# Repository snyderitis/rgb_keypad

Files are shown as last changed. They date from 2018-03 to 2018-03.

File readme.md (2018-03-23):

# 20keyrgb

20keyrgb

A short description of the keyboard/project

Keyboard Maintainer: [Snyderitis](https://github.com/snyderitis)  
Hardware Supported: The kicad files for the PCB are in the "RGB keyboard" folder. 
Hardware Availability: I used WS2812B leds with 0.1uF SMD capacitors and a teensy. In the future it would be wiser to use an Arduino Pro mini as they're essentially the same and have the same pin layout.

Make example for this keyboard (after setting up your build environment):

    make 20keyrgb:default

See [build environment setup](https://docs.qmk.fm/build_environment_setup.html) then the [make instructions](https://docs.qmk.fm/make_instructions.html) for more information.

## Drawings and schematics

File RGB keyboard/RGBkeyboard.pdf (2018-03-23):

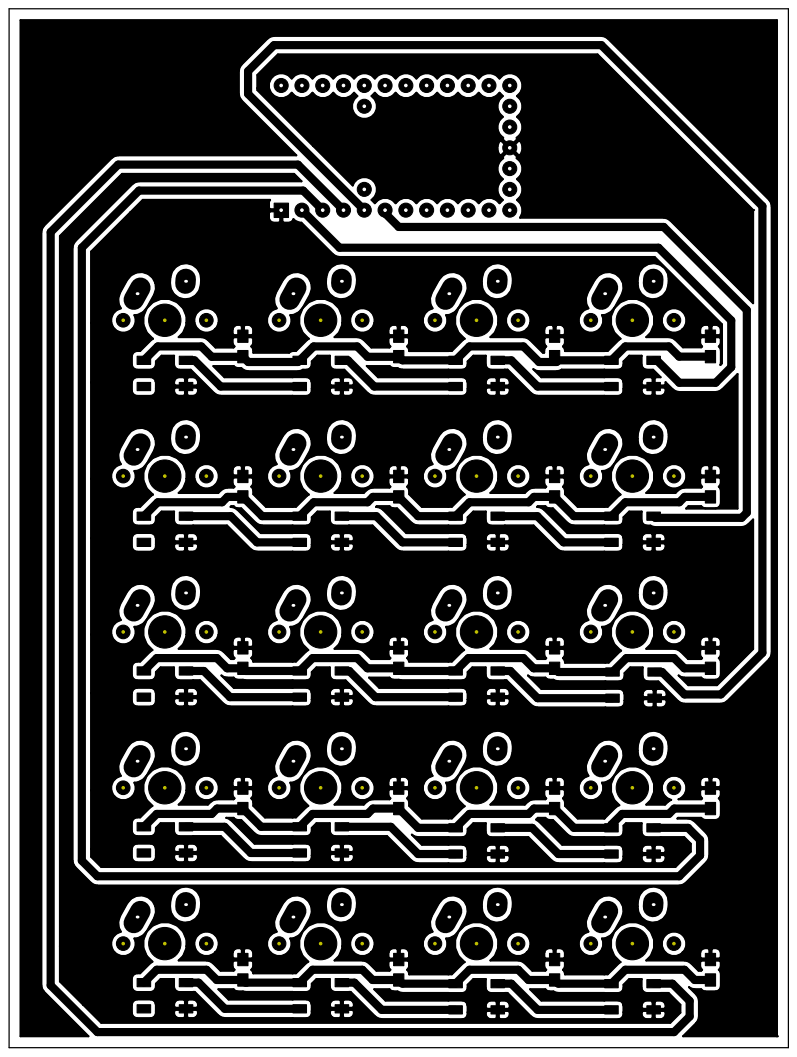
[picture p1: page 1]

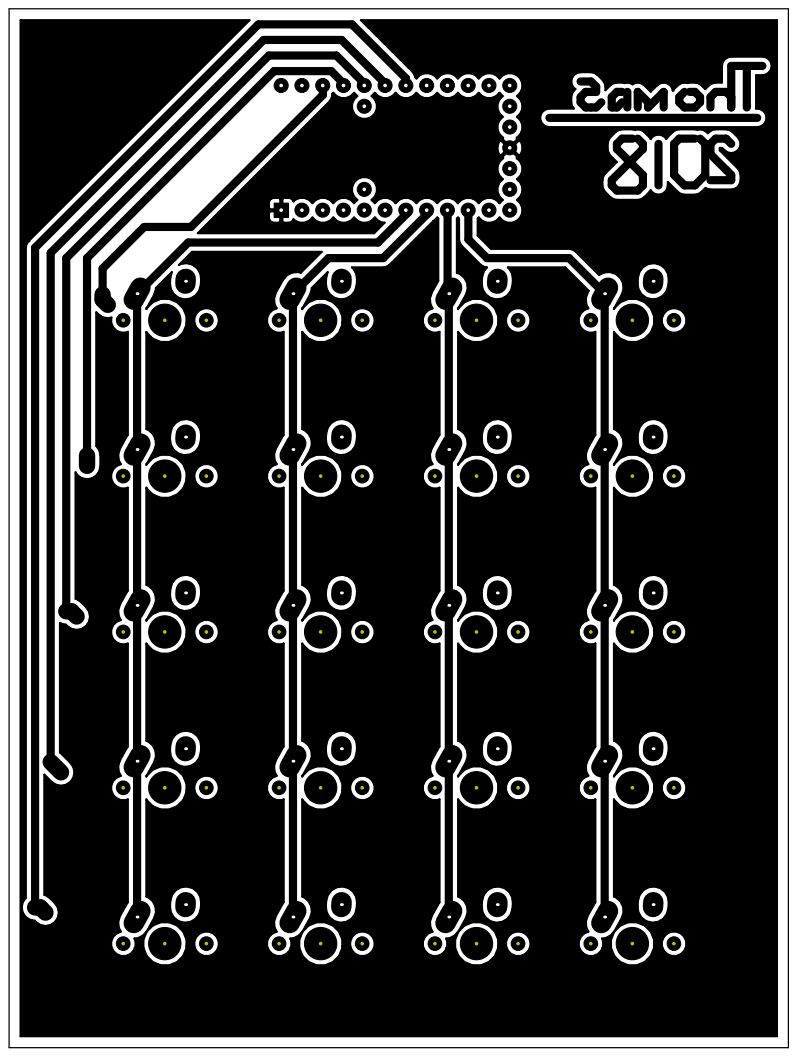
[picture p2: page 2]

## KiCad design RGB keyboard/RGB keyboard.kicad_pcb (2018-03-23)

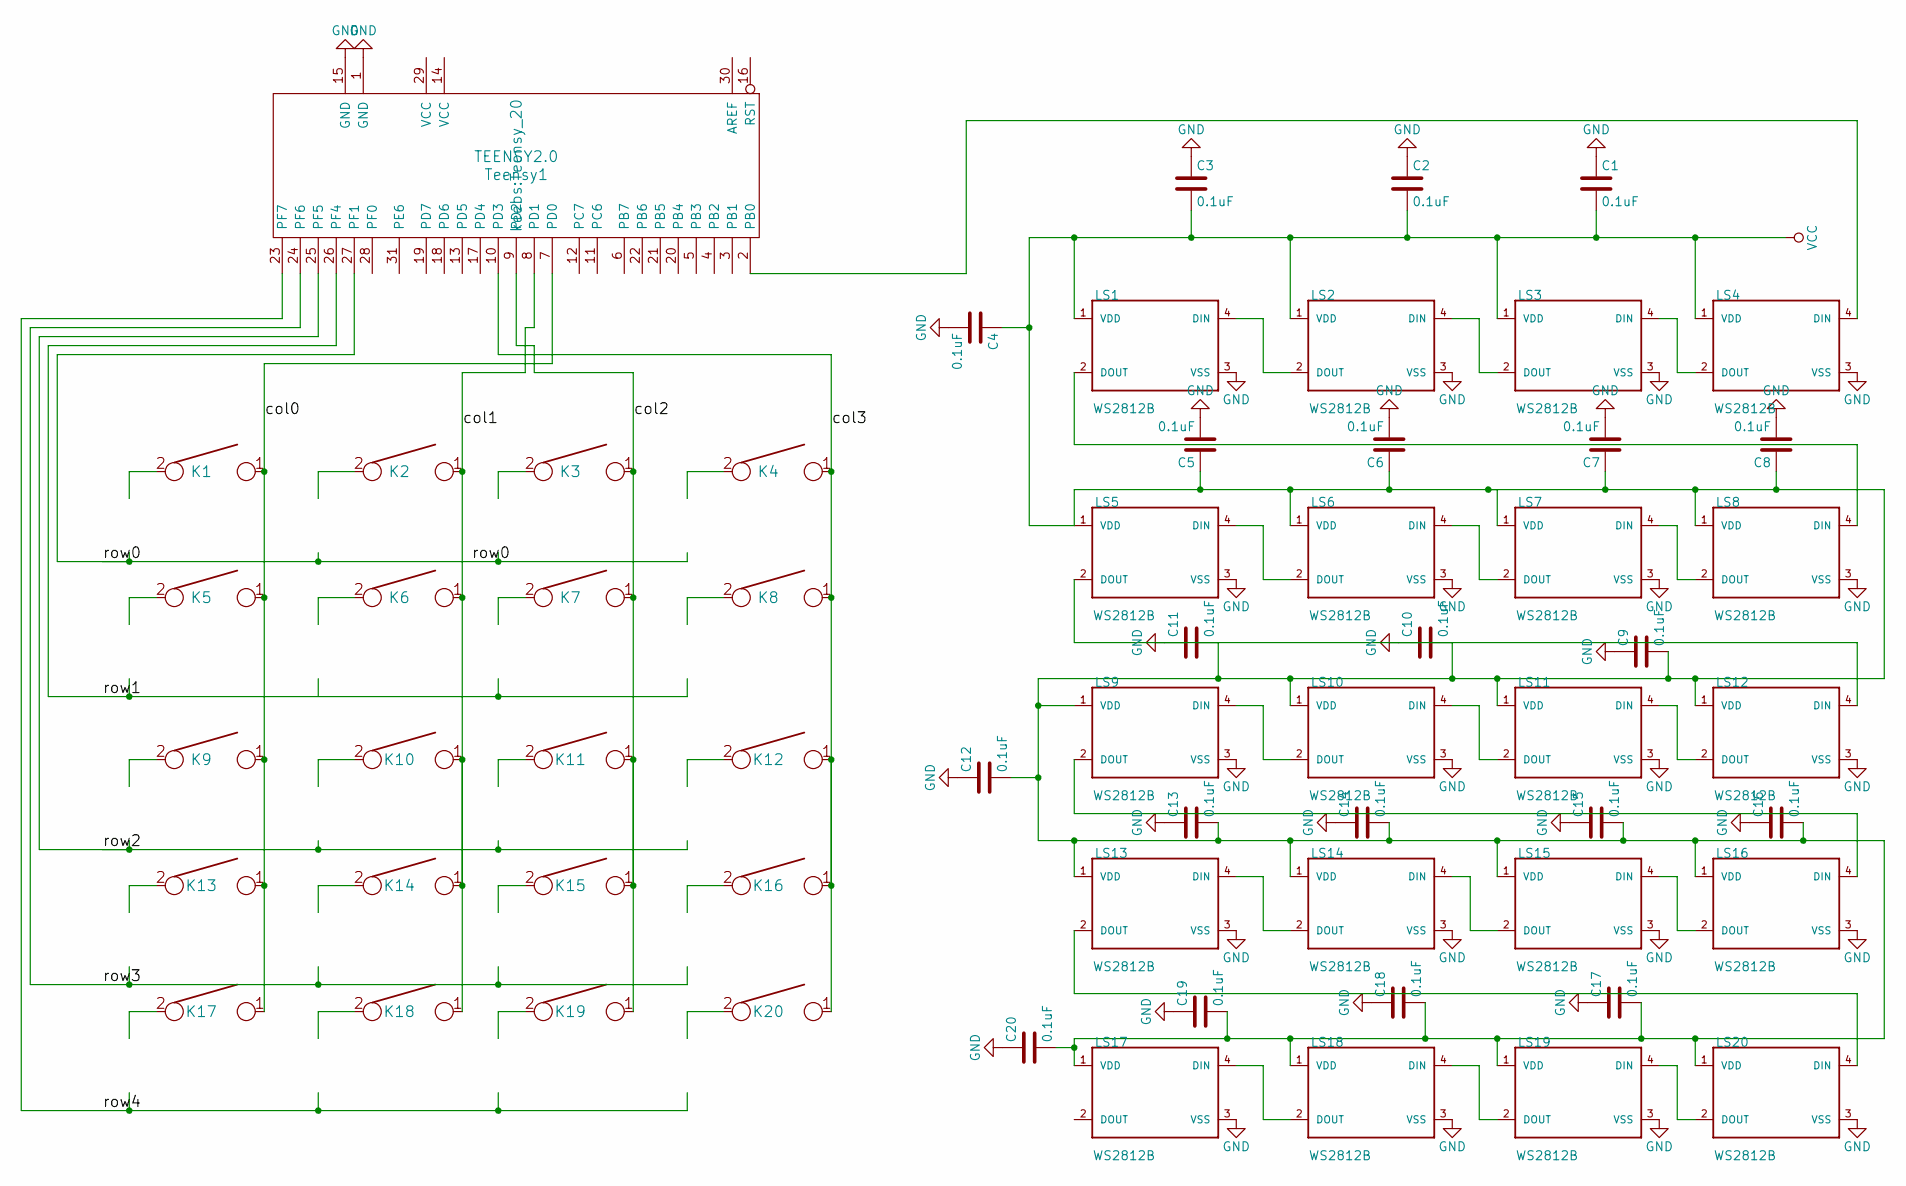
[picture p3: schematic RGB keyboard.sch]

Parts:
C1, C2, C3, C4, C5, C6, C7, C8, C9, C10, C11, C12, C13, C14, C15, C16, C17, C18, C19, C20: 0.1uF; C_0805_HandSoldering
K1, K2, K3, K4, K5, K6, K7, K8, K9, K10, K11, K12, K13, K14, K15, K16, K17, K18, K19, K20: KEYSW; Mx_Alps_100
LS1, LS2, LS3, LS4, LS5, LS6, LS7, LS8, LS9, LS10, LS11, LS12, LS13, LS14, LS15, LS16, LS17, LS18, LS19, LS20: WS2812B
Teensy1: TEENSY2.0; Teensy_20

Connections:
/col0: K1.1, K5.1, K9.1, K13.1, K17.1, Teensy1.7 (PD0)
/col1: K2.1, K6.1, K10.1, K14.1, K18.1, Teensy1.8 (PD1)
/col2: K3.1, K7.1, K11.1, K15.1, K19.1, Teensy1.9 (PD2)
/col3: K4.1, K8.1, K12.1, K16.1, K20.1, Teensy1.10 (PD3)
/row0: Teensy1.27 (PF1)
/row1: Teensy1.26 (PF4)
/row2: Teensy1.25 (PF5)
/row3: Teensy1.24 (PF6)
/row4: Teensy1.23 (PF7)
unnamed: LS1.2 (DOUT), LS8.4 (DIN)
unnamed: LS1.4 (DIN), LS2.2 (DOUT)
unnamed: LS2.4 (DIN), LS3.2 (DOUT)
unnamed: LS3.4 (DIN), LS4.2 (DOUT)
unnamed: LS4.4 (DIN), Teensy1.2 (PB0)
unnamed: LS5.4 (DIN), LS6.2 (DOUT)
unnamed: LS6.4 (DIN), LS7.2 (DOUT)
unnamed: LS7.4 (DIN), LS8.2 (DOUT)
unnamed: LS9.4 (DIN), LS10.2 (DOUT)
unnamed: LS10.4 (DIN), LS11.2 (DOUT)
unnamed: LS11.4 (DIN), LS12.2 (DOUT)
unnamed: LS13.2 (DOUT), LS20.4 (DIN)
unnamed: LS13.4 (DIN), LS14.2 (DOUT)
unnamed: LS14.4 (DIN), LS15.2 (DOUT)
unnamed: LS15.4 (DIN), LS16.2 (DOUT)
unnamed: LS9.2 (DOUT), LS16.4 (DIN)
unnamed: LS17.4 (DIN), LS18.2 (DOUT)
unnamed: LS18.4 (DIN), LS19.2 (DOUT)
unnamed: LS19.4 (DIN), LS20.2 (DOUT)
VCC: C1.2, C2.2, C3.2, C4.1, C5.1, C6.1, C7.1, C8.1, C9.2, C10.2, C11.2, C12.2, C13.2, C14.2, C15.2, C16.2, C17.2, C18.2, C19.2, C20.2, LS1.1 (VDD), LS2.1 (VDD), LS3.1 (VDD), LS4.1 (VDD), LS5.1 (VDD), LS6.1 (VDD), LS7.1 (VDD), LS8.1 (VDD), LS9.1 (VDD), LS10.1 (VDD), LS11.1 (VDD), LS12.1 (VDD), LS13.1 (VDD), LS14.1 (VDD), LS15.1 (VDD), LS16.1 (VDD), LS17.1 (VDD), LS18.1 (VDD), LS19.1 (VDD), LS20.1 (VDD)

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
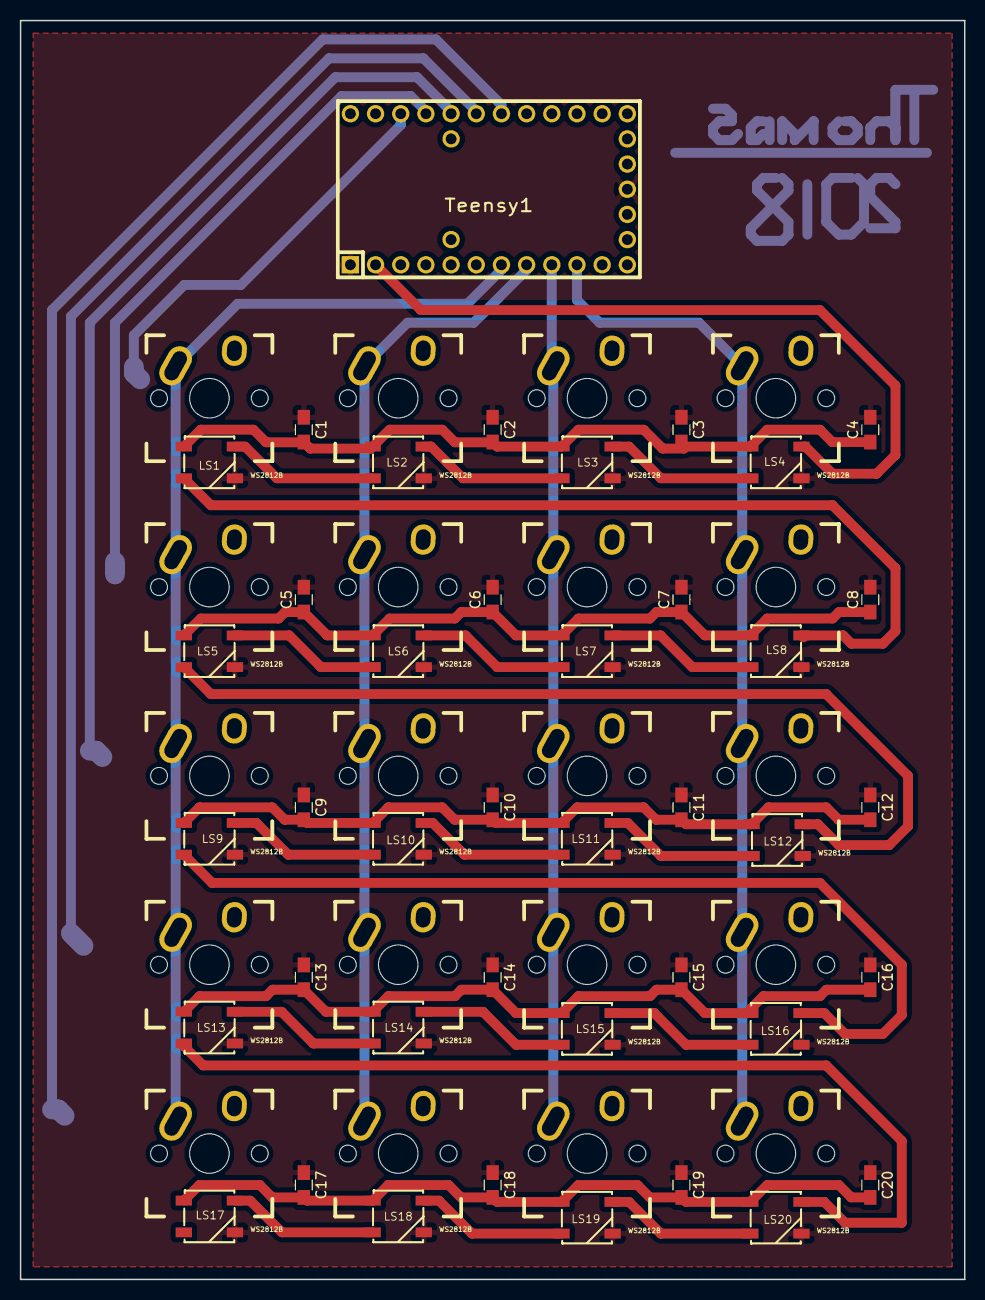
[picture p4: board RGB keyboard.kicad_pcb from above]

Board: 2 copper layers, 95.2 x 127.0 mm, 61 parts (0 on the bottom side), 26 nets.

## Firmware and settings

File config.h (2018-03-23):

/*
Copyright 2017 REPLACE_WITH_YOUR_NAME

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
You should have received a copy of the GNU General Public License
along with this program.  If not, see <http://www.gnu.org/licenses/>.
*/

#ifndef CONFIG_H
#define CONFIG_H

#include "config_common.h"
#include "stdlib.h"
#include "time.h"
#include "math.h"
#ifndef PI
#define PI 3.14159265359
#endif

/* USB Device descriptor parameter */
#define VENDOR_ID       0xFEED
#define PRODUCT_ID      0x0000
#define DEVICE_VER      0x0001
#define MANUFACTURER    Snyderitis
#define PRODUCT         20keyrgb
#define DESCRIPTION     RGB keypad

/* key matrix size */
#define MATRIX_ROWS 5
#define MATRIX_COLS 4

/*
 * Keyboard Matrix Assignments
 *
 * Change this to how you wired your keyboard
 * COLS: AVR pins used for columns, left to right
 * ROWS: AVR pins used for rows, top to bottom
 * DIODE_DIRECTION: COL2ROW = COL = Anode (+), ROW = Cathode (-, marked on diode)
 *                  ROW2COL = ROW = Anode (+), COL = Cathode (-, marked on diode)
 *
*/
#define MATRIX_COL_PINS { D0, D1, D2, D3 }//{ D3, D2, D1, D0 }
#define MATRIX_ROW_PINS { F1, F4, F5, F6, F7 }
#define UNUSED_PINS

/* COL2ROW, ROW2COL, or CUSTOM_MATRIX */
#define DIODE_DIRECTION COL2ROW
 
// #define BACKLIGHT_PIN B7
// #define BACKLIGHT_BREATHING
// #define BACKLIGHT_LEVELS 3


/* Debounce reduces chatter (unintended double-presses) - set 0 if debouncing is not needed */
#define DEBOUNCING_DELAY 5

/* define if matrix has ghost (lacks anti-ghosting diodes) */
//#define MATRIX_HAS_GHOST

/* number of backlight levels */

/* Mechanical locking support. Use KC_LCAP, KC_LNUM or KC_LSCR instead in keymap */
//#define LOCKING_SUPPORT_ENABLE
/* Locking resynchronize hack */
//#define LOCKING_RESYNC_ENABLE

/* If defined, GRAVE_ESC will always act as ESC when CTRL is held.
 * This is userful for the Windows task manager shortcut (ctrl+shift+esc).
 */
// #define GRAVE_ESC_CTRL_OVERRIDE
/*
 * Force NKRO
 *
 * Force NKRO (nKey Rollover) to be enabled by default, regardless of the saved
 * state in the bootmagic EEPROM settings. (Note that NKRO must be enabled in the
 * makefile for this to work.)
 *
 * If forced on, NKRO can be disabled via magic key (default = LShift+RShift+N)
 * until the next keyboard reset.
 *
 * NKRO may prevent your keystrokes from being detected in the BIOS, but it is
 * fully operational during normal computer usage.
 *
 * For a less heavy-handed approach, enable NKRO via magic key (LShift+RShift+N)
 * or via bootmagic (hold SPACE+N while plugging in the keyboard). Once set by
 * bootmagic, NKRO mode will always be enabled until it is toggled again during a
 * power-up.
 *
 */
//#define FORCE_NKRO

/*
 * Magic Key Options
 *
 * Magic keys are hotkey commands that allow control over firmware functions of
 * the keyboard. They are best used in combination with the HID Listen program,
 * found here: https://www.pjrc.com/teensy/hid_listen.html
 *
 * The options below allow the magic key functionality to be changed. This is
 * useful if your keyboard/keypad is missing keys and you want magic key support.
 *
 */

/* key combination for magic key command */
#define IS_COMMAND() ( \
    keyboard_report->mods == (MOD_BIT(KC_LSHIFT) | MOD_BIT(KC_RSHIFT)) \
)

/* control how magic key switches layers */
//#define MAGIC_KEY_SWITCH_LAYER_WITH_FKEYS  true
//#define MAGIC_KEY_SWITCH_LAYER_WITH_NKEYS  true
//#define MAGIC_KEY_SWITCH_LAYER_WITH_CUSTOM false

/* override magic key keymap */
//#define MAGIC_KEY_SWITCH_LAYER_WITH_FKEYS
//#define MAGIC_KEY_SWITCH_LAYER_WITH_NKEYS
//#define MAGIC_KEY_SWITCH_LAYER_WITH_CUSTOM
//#define MAGIC_KEY_HELP1          H
//#define MAGIC_KEY_HELP2          SLASH
//#define MAGIC_KEY_DEBUG          D
//#define MAGIC_KEY_DEBUG_MATRIX   X
//#define MAGIC_KEY_DEBUG_KBD      K
//#define MAGIC_KEY_DEBUG_MOUSE    M
//#define MAGIC_KEY_VERSION        V
//#define MAGIC_KEY_STATUS         S
//#define MAGIC_KEY_CONSOLE        C
//#define MAGIC_KEY_LAYER0_ALT1    ESC
//#define MAGIC_KEY_LAYER0_ALT2    GRAVE
//#define MAGIC_KEY_LAYER0         0
//#define MAGIC_KEY_LAYER1         1
//#define MAGIC_KEY_LAYER2         2
//#define MAGIC_KEY_LAYER3         3
//#define MAGIC_KEY_LAYER4         4
//#define MAGIC_KEY_LAYER5         5
//#define MAGIC_KEY_LAYER6         6
//#define MAGIC_KEY_LAYER7         7
//#define MAGIC_KEY_LAYER8         8
//#define MAGIC_KEY_LAYER9         9
//#define MAGIC_KEY_BOOTLOADER     PAUSE
//#define MAGIC_KEY_LOCK           CAPS
//#define MAGIC_KEY_EEPROM         E
//#define MAGIC_KEY_NKRO           N
//#define MAGIC_KEY_SLEEP_LED      Z

/*
 * Feature disable options
 *  These options are also useful to firmware size reduction.
 */

/* disable debug print */
//#define NO_DEBUG

/* disable print */
//#define NO_PRINT

/* disable action features */
//#define NO_ACTION_LAYER
//#define NO_ACTION_TAPPING
//#define NO_ACTION_ONESHOT
//#define NO_ACTION_MACRO
//#define NO_ACTION_FUNCTION

/*
 * MIDI options
 */
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

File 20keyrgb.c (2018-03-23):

/* Copyright 2017 REPLACE_WITH_YOUR_NAME
 *
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
 * You should have received a copy of the GNU General Public License
 * along with this program.  If not, see <http://www.gnu.org/licenses/>.
 */
#include "20keyrgb.h"
#include "led.h"
//#include <print.h>
int huey;
int light_step = 5;
int stepper;

bool has_layer_changed = false;
static uint8_t current_layer;
uint8_t layer;
int swirl_offset;

void matrix_init_kb(void) {
	// put your keyboard start-up code here
	// runs once when the firmware starts up
  srand(time(NULL)); //For rand function in rgblight animations
  huey = 0;
  swirl_offset = 0;
  light_mode = 0;
  stepper = 0;
	matrix_init_user();
  max_rgb_val = 100;
  rainbow_freq = 5;
  light_speed = 1;
  layer = biton32(layer_state);
  inc_val = 15;
  for (int i = 0; i < RGBLED_NUM; i++)
  {
    light_hue[i] = 0;
    light_val[i] = 0;
  }
}

void matrix_scan_kb(void) {
	// put your looping keyboard code here
	// runs every cycle (a lot)
  //print("Working");
  
	matrix_scan_user();
  if (check_change_layer())
  {
    rgblight_sethsv(0, 0, 0);
    for (int i = 0; i < 60; i++)
      disp_rgb_num(current_layer);
    rgblight_sethsv(0, 0, 0);
  }
  rgb_lights(light_mode);
  


}



bool check_change_layer(void)
{
  //checks layer change
  layer = biton32(layer_state);
  if (current_layer == layer) {
    return false;
  }
  else {
     current_layer = layer;
     return true;
  }
}
//This updates the appropriate things
void rgb_lights(int modey)
{
  switch (modey)
  {
  case RAINBOW_MODE:
    my_rainbow_lights();
    break;
  case RANDOM_MODE:
    my_random_lights();
    break;
  case RAND_REACTIVE_MODE:
    update_rand_react();
    break;
  case RNBW_SWRL_MODE:
    my_rainbow_swirl();
    break;
  default:
    rgblight_sethsv(0, 0, 0);
    break;
  }

}


void my_rainbow_swirl(void)
{
  swirl_offset+=5;
  if (swirl_offset >= 360)
  {
    swirl_offset = 0;
  }
  for (int row = 0; row < MATRIX_ROWS; row++)
  {
    for (int col = 0; col < MATRIX_COLS; col++)
    {
      float cCol = 1.5 - col;
      float cRow = 2 - row;
      //negative or positive within a tan switches rotation direction
      double deg = atan(-cRow / cCol) * 180 / PI;
      //These make some pretty cool stuff
      //double deg = atan(cCol/cRow) * 180 / PI;
      //double hyp = sqrt(pow(cCol, 2) + pow(cRow, 2));
      // double deg = asin(cRow / hyp) * 180 / PI;
      // double deg = asin(cCol / hyp) * 180 / PI;
      //double deg = acos(cCol / hyp) * 180 / PI;
      //double deg = acos(cRow / hyp) * 180 / PI;

      int hue = (int)deg + swirl_offset;
      
      if (hue >= 360)
      {
        hue -= 360;
      }
      else if (hue < 0) hue += 360;
      int ind = col + (row * 4);
      rgblight_sethsv_at(hue, 255, max_rgb_val, ind);
      light_hue[ind] = hue;
      light_val[ind] = max_rgb_val;
    }

  }
}


//choose a random light, light it up, fade it out
void my_random_lights(void)
{
  int curr_led = rand() % 20;
  if (light_val[curr_led] == 0) {
    int new_hue = rand() % 360;
    rgblight_sethsv_at(new_hue, 255, max_rgb_val, curr_led);
    light_hue[curr_led] = new_hue;
    light_val[curr_led] = max_rgb_val;
  }
  for (int i = 0; i < RGBLED_NUM; i++)
  {
    if (light_val[i] > 0)
      light_val[i] -= light_step;
    rgblight_sethsv_at(light_hue[i], 255, light_val[i], i);
  }
}

//gradient rainbow
void my_rainbow_lights(void) {
  if (stepper >= light_speed)
  {
    stepper = 0;
    huey++;
  }

  stepper++;
  if (huey >= 360)
  {
    huey = 0;
  }
  for (int i = 0; i < RGBLED_NUM; i++) {
    if (huey + (i*rainbow_freq) < 360) {
      rgblight_sethsv_at(huey + (i*rainbow_freq), 255, max_rgb_val, i);
      light_hue[i] = huey + (i*rainbow_freq);
    }
    else {
      rgblight_sethsv_at(huey + (i*rainbow_freq) - 360, 255, max_rgb_val, i);
      light_hue[i] = huey + (i*rainbow_freq) - 360;
    }
    light_val[i] = max_rgb_val;
  }
}



void disp_rgb_num(int num)
{
  
  switch (num)
  {
  case 0:
    for (int i = 0; i < RGBLED_NUM; i++)
    {
      if (i == 1 || i == 2 || i == 4 || i == 7 || i == 8 || i == 11 || i == 12 || i == 15 || i == 17 || i == 18)
        rgblight_sethsv_at(0, 0, max_rgb_val, i);
    }
  break;
  case 1:
    for (int i = 0; i < RGBLED_NUM; i++)
    {
      if (i == 1 || i == 5 || i == 6 || i == 9 || i == 13 || i == 17)
        rgblight_sethsv_at(0, 0, max_rgb_val, i);
    
    }break;
  case 2:
    for (int i = 0; i < RGBLED_NUM; i++)
    {
      if (i == 1 || i == 2 || i == 4 || i == 7 || i == 9 || i == 14 || i > 15)
        rgblight_sethsv_at(0, 0, max_rgb_val, i);
    }
    break;
  }
}

bool process_record_kb(uint16_t keycode, keyrecord_t *record) {
	// put your per-action keyboard code here
	// runs for every action, just before processing by the firmware

	return process_record_user(keycode, record);
}

void led_set_kb(uint8_t usb_led) {
	// put your keyboard LED indicator (ex: Caps Lock LED) toggling code here

	led_set_user(usb_led);
}


void update_rand_react(void)
{
  if (stepper == 10) {
    stepper = 0;
    for (int i = 0; i < RGBLED_NUM; i++)
    {
      if (light_val[i] > 0) {
        light_val[i]--;
        rgblight_sethsv_at(light_hue[i], 255, light_val[i], i);
      }
    }
  }else
    stepper++;
}


void rgb_react(int row, int col)
{
  col = 3 - col; //flip cols because 0,0 in keys is opposite 0,0 in leds
  int led_ind = col + (row*4);
  int huey = rand() % 360;
  light_hue[led_ind] = huey;
  light_val[led_ind] = max_rgb_val;
  rgblight_sethsv_at(huey, 255, max_rgb_val, led_ind);
}

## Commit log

2018-03-23 added kicad files
    [RGB keyboard-B.Cu.gbr, RGB keyboard-B.Mask.gbr, RGB keyboard-B.SilkS.gbr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]
2018-03-23 Commented switch cases for rgbs

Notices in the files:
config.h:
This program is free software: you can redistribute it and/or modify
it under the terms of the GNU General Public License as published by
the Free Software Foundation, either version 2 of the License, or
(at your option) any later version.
